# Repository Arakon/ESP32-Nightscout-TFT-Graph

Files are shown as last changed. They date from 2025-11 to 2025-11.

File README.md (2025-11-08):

# ESP32-Nightscout-TFT-Graph
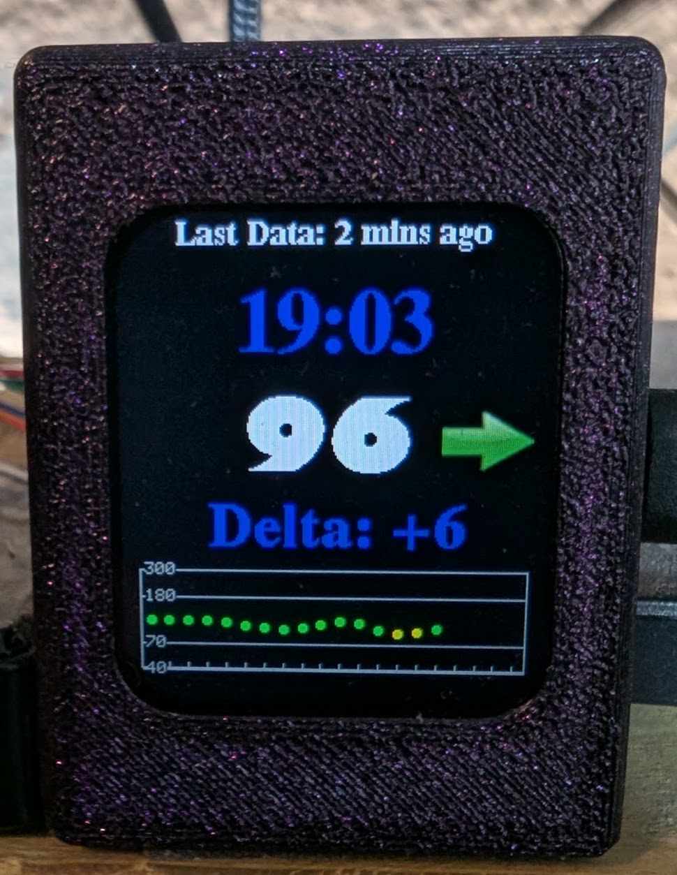
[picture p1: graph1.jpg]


ESP32-C3 based low cost desktop display for Nightscout Glucose

Display supported:

1.69" 240x280:
https://www.aliexpress.com/item/1005008136222795.html

ESP32-C3:
https://www.aliexpress.com/item/1005006599448997.html

[Wiring diagram](https://github.com/Arakon/ESP32-Nightscout-TFT-Graph/blob/main/wiring-C3.png)

If you want to flash the [binary](https://github.com/Arakon/ESP32-Nightscout-TFT-Graph/blob/main/ESP32-C3-Nightscout-TFT-Graph.bin) directly, get [esptool](https://github.com/espressif/esptool/releases/download/v4.10.0/esptool-v4.10.0-windows-amd64.zip), extract it, copy the ESP32-C3-Nightscout-TFT-Graph.bin to the same folder, then open a command prompt, navigate to the folder you extracted it to, and run:

`esptool --port COMxx write_flash 0x0 ESP32-C3-Nightscout-TFT-Graph.bin`

Replace "COMxx" with your COM port number of the ESP32-C3 (i.e. COM5)

Use Arduino IDE 2.3.5 or 2.3.6 to compile.

**Required libraries to install: LovyanGFX 1.2.7, ArduinoJSON 7.4.1, WiFiManger 2.0.17, ESP_MultiResetDetector 1.3.2**

Newer versions may work, but these are known working.

**It's critical that you install/downgrade the ESP32 Board version to _2.0.14_!**

Versions 3+ will not fit the available memory and also cause compile errors with LGFX, while versions >2.0.14 can cause a reset loop on the C3.

As board type, select the **LOLIN C3 Mini** if you are using the above ESP32-C3 SuperMini.

STL files are provided for the display, put the display in first so it is held by the hooks (note the indent, this is where the bottom of the display with the flex cable goes), put the plate on the back, then glue the ESP32-C3 into the provided space (thick doublesided tape recommended). Attach the plate on all 4 sides with a bit of hotglue. Finally, pop the lid on, noting the direction so that the button is above the ESP32's reset button.
If you need to get back in there for any reason, isopropyl alcohol will instantly release hotglue.
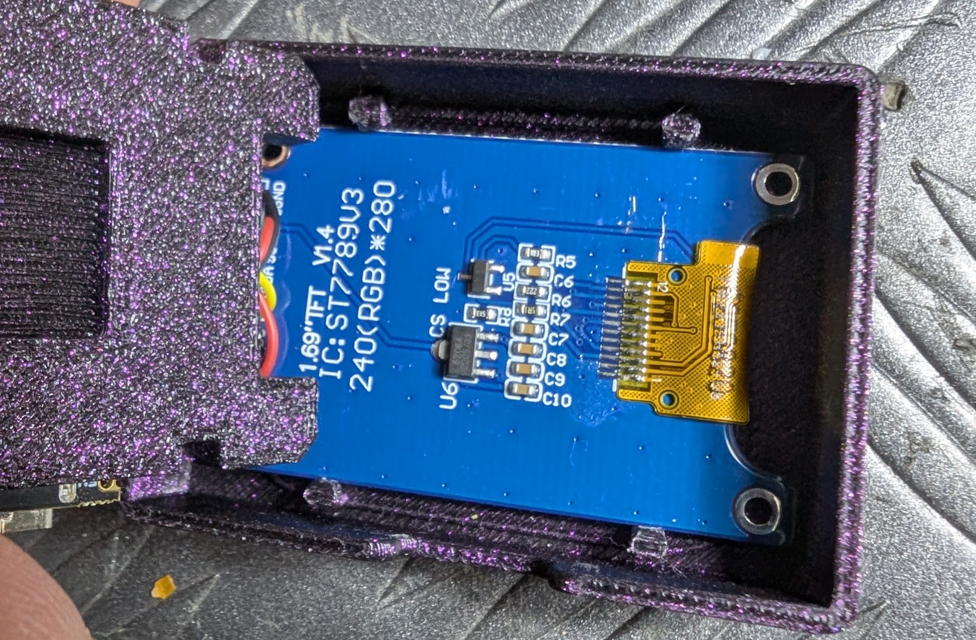
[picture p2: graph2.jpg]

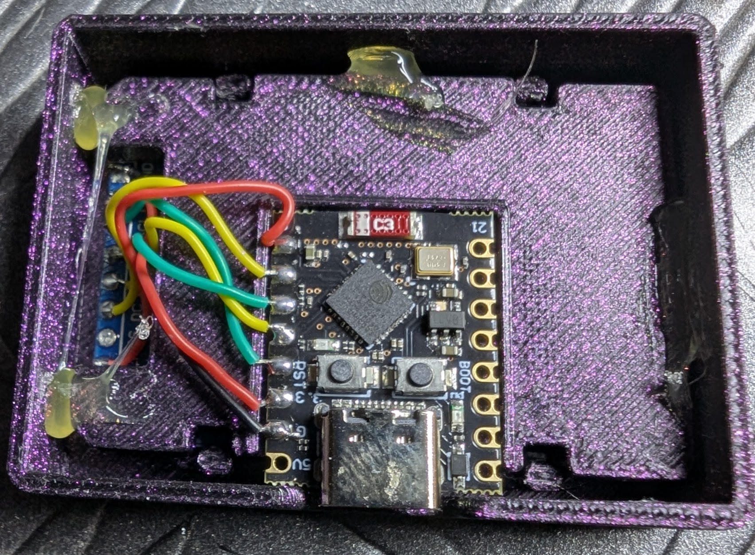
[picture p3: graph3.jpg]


Once the device starts for the first time, connect your WiFi (cellphone or PC) to the access point "Nightscout-TFT" that becomes available. Enter the password shown on the screen, then visit http://192.168.4.1 in your webbrowser.
You can set up your nightscout instance (add the _/pebble_ at the end like the example! You also need a [token with viewing rights](https://nightscout.github.io/nightscout/security/#create-a-token).) and your home WiFi there.

There is some oddity with the MultiResetDetector library that causes it to sometimes enter config mode when plugged in. Unplugging and plugging back in fixes this usually.

**First** run the Setup tab, with your Nightscout data, High/Low/Critical values and background light strength.

**Afterwards** you will have to reconnect to the access point again and this time, set up the WiFi connection.

Once everything is connected, you should get a full display. If it hangs, try unplugging, waiting for a moment, and plugging it back in.
If you ever want to change any of the options, quickly **tripleclick** the Reset button within 5 seconds on the ESP32 to force config mode. Wait for the yellow text before pressing the button each time. This will require you to connect to the Nightscout-TFT access point again with the password displayed on the screen.

The graph will populate as values arrive, it takes 100 minutes/20 updates to fully fill it.

Some status info is available on the serial monitor via USB (115200 baud).

Partially based on [Gluci-Clock](https://github.com/Frederic1000/gluci-clock/) and my own [Nightscout-TFT](https://github.com/Arakon/Nightscout-TFT).

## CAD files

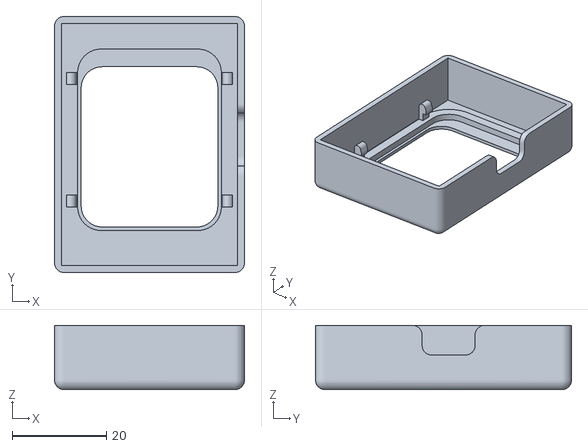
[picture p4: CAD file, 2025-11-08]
STL/case.stl
40.3 x 54.3 x 13.6

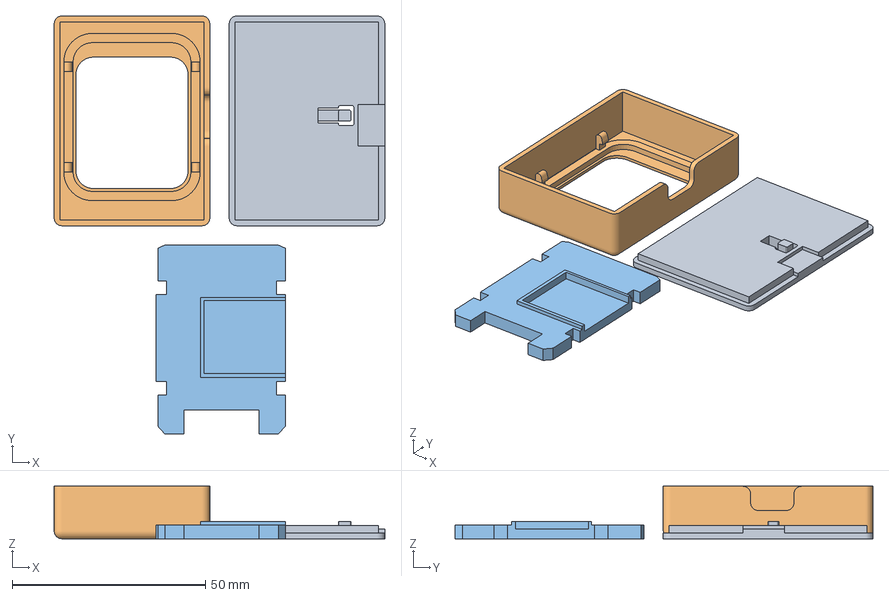
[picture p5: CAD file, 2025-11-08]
STL/1.69-Case.3mf
85.6 x 108.2 x 13.6 mm
lid.stl
case.stl
plate.stl

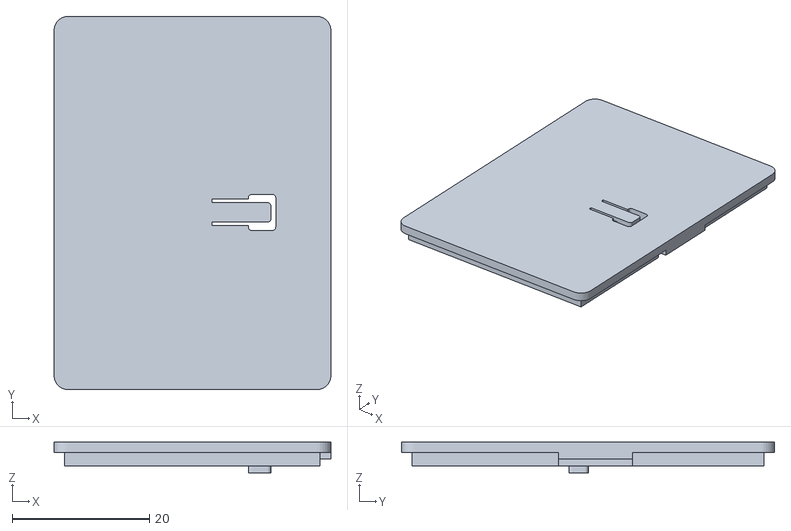
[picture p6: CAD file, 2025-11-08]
STL/lid.stl
40.3 x 54.3 x 4.50

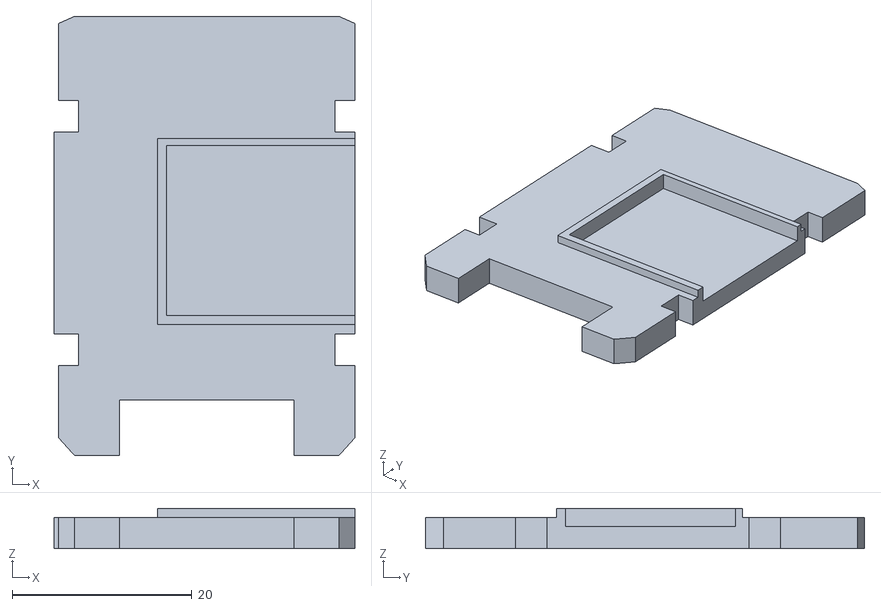
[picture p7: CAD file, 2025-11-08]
STL/plate.stl
33.5 x 48.9 x 4.50

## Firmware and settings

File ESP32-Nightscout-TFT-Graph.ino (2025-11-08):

/**
Nightscout glucose display for use with ESPS32-C3 and 1.3" or 1.54" SPI screen.
Based partially on my original version of this for ESP8266: https://github.com/Arakon/Nightscout-TFT
and gluci-clock by Frederic1000: https://github.com/Frederic1000/gluci-clock
Also compatible with other ESP32 devices, but may require pin reassignments below.

*/

// install libraries: WifiManager, arduinoJson, ESP_MultiResetDetector, LovyanGFX


// In the Arduino IDE, select Board Manager and downgrade to ESP32 2.0.14, ESP32 3.x based will NOT fit most smaller ESP32 boards anymore.

#include <Arduino.h>
#include <WiFi.h>
#include <FS.h>
#include <SPIFFS.h>
#include <HTTPClient.h>
#include <time.h>
#include <ArduinoJson.h>
#include <SPI.h>
#include <WiFiManager.h>

//including the arrow images
#include "Flat.h"
#include "DoubleDown.h"
#include "DoubleUp.h"
#include "FortyFiveUp.h"
#include "FortyFiveDown.h"
#include "Up.h"
#include "Down.h"
#define ESP_MRD_USE_SPIFFS true

#define GFXFF 1
#include <LovyanGFX.hpp>
#include "_19_font28pt7b.h"  //Numbers font for the Glucose number

//setup for LovyanGFX, all settings are in tft_config.h - Adjust to match your display if needed
#include "tft_config.h"
LGFX_Sprite sprite(&tft);

int hour_c;
int min_c;

// Defaults for when the color of the glucose value changes, edit them in the web interface
int HighBG = 180;
int LowBG = 90;
int CritBG = 70;

// --- Graph configuration ---
static const int GRAPH_WIDTH = 220;
static const int GRAPH_HEIGHT = 60;
static const int GRAPH_X = 10;
static const int GRAPH_Y = 200;

static const int MAX_POINTS = 20;
int sgv_values[MAX_POINTS] = { 0 };
int sgv_count = 0;

// -------------------------------------
// -------   Other Config   ------
// -------------------------------------

const int PIN_LED = LED_BUILTIN;  // default onboard LED
int backlight = 64;               //default brightness

#define JSON_CONFIG_FILE "/config.json"

// Number of seconds after reset during which a
// subseqent reset will be considered a triple reset.
#define MRD_TIMES 3
#define MRD_TIMEOUT 10
#define MRD_ADDRESS 0
#include <ESP_MultiResetDetector.h>
MultiResetDetector* mrd;
//flag for saving data
bool shouldSaveConfig = false;


// url and API key defaults for Nightscout - Set in the web portal
// We use the /pebble API since it contains the delta value. Don't remove the /pebble at the end!
char NS_API_URL[150] = "http://yournightscoutwebsite/pebble";

// Create a token with read access in NS > Hamburger menu > Admin tools
// Enter the token in the web portal
char NS_API_SECRET[50] = "view-123456790";


// Parameters for time NTP server
char ntpServer1[50] = "pool.ntp.org";
char ntpServer2[50] = "de.pool.ntp.org";

// Time zone for local time and daylight saving, edit in web interface
// list here:
// https://github.com/nayarsystems/posix_tz_db/blob/master/zones.csv
char local_time_zone[50] = "CET-1CEST,M3.5.0,M10.5.0/3";  // set for Europe/Berlin
char utc_time_zone[] = "GMT0";
int gmtOffset_sec = 3600;
long daylightOffset_sec = 3600;

// time zone offset in minutes, initialized to UTC
int tzOffset = 0;

void drawScreen(long sgv, int trend, int bg_delta, int elapsed_mn, const struct tm& tm) {
  sprite.fillScreen(TFT_BLACK);

  // ----------------------------
  // "Last Data" age display
  // ----------------------------
  int agecol = (elapsed_mn >= 15) ? TFT_RED : TFT_WHITE;  // change color if data is over 15 minutes old
  int agepos = (elapsed_mn >= 100)  ? 19                  // change position depending on number of digits
               : (elapsed_mn >= 10) ? 26
                                    : 33;

  sprite.setFont(&fonts::FreeSerifBold9pt7b);
  sprite.setTextColor(agecol, TFT_BLACK);
  sprite.setCursor(agepos, 4);
  sprite.printf("Last Data: %d min%s ago", elapsed_mn, (elapsed_mn == 1) ? "" : "s");  // add "s" to "mins" if >1

  // ----------------------------
  // Clock
  // ----------------------------
  sprite.setFont(&fonts::FreeSerifBold24pt7b);
  sprite.setTextColor(TFT_BLUE, TFT_BLACK);
  sprite.setCursor(65, 40);
  sprite.printf("%02d:%02d", tm.tm_hour, tm.tm_min);

  // ----------------------------
  // Glucose value
  // ----------------------------
  int bgcol = TFT_WHITE;
  if (sgv >= HighBG) bgcol = TFT_ORANGE;
  else if ((sgv <= LowBG) && (sgv > CritBG)) bgcol = TFT_YELLOW;
  else if (sgv <= CritBG) bgcol = TFT_RED;

  sprite.setFont(&_19_font28pt7b);
  sprite.setTextColor(bgcol, TFT_BLACK);
  sprite.setCursor((sgv < 100) ? 70 : 30, 100);  // adjust depending on whether the value has 2 or 3 digits
  sprite.println(sgv);

  // ----------------------------
  // Trend arrow
  // ----------------------------
  sprite.setSwapBytes(true);
  const uint16_t* arrowImg = nullptr;
  switch (trend) {
    case 1: arrowImg = DoubleUp; break;
    case 2: arrowImg = Up; break;
    case 3: arrowImg = FortyFiveUp; break;
    case 4: arrowImg = Flat; break;
    case 5: arrowImg = FortyFiveDown; break;
    case 6: arrowImg = Down; break;
    case 7: arrowImg = DoubleDown; break;
  }
  if (arrowImg) {
    sprite.pushImage(180, 100, 50, 50, arrowImg);
  }

  // ----------------------------
  // Delta
  // ----------------------------
  sprite.setFont(&fonts::FreeSerifBold18pt7b);
  sprite.setTextColor(TFT_BLUE, TFT_BLACK);
  sprite.setCursor((bg_delta >= 10) ? 37 : 49, 160);
  sprite.printf("Delta: %+d", bg_delta);
  drawSGVGraph(sprite);
  sprite.pushSprite(0, 0);
}

void drawSGVGraph(LGFX_Sprite& sprite) {

  // --- Define graph area ---
  int x0 = GRAPH_X;
  int y0 = GRAPH_Y;
  int w = GRAPH_WIDTH;
  int h = GRAPH_HEIGHT;

  // --- Clear graph area ---
  sprite.fillRect(x0, y0, w, h, TFT_BLACK);
  sprite.drawRect(x0, y0, w, h, TFT_DARKGREY);

  if (sgv_count == 0) return;

  const float MIN_SGV = 40.0f;
  const float MAX_SGV = 300.0f;
  const float LOG_BASE = 1.03f;
  auto logb = [&](float v) {
    return logf(v) / logf(LOG_BASE);
  };

  // compute consistent min/max
  float log_min = logb(MIN_SGV);
  float log_max = logb(MAX_SGV);

  // --- Draw Y-axis labels (SGV range) ---
  const int gridLevels[] = { 40, CritBG, HighBG, 300 };
  const int gridCount = sizeof(gridLevels) / sizeof(gridLevels[0]);
  sprite.setTextColor(TFT_DARKGREY, TFT_BLACK);
  sprite.setTextDatum(TL_DATUM);
  sprite.setFont(&fonts::Font0);
  for (int i = 0; i < gridCount; i++) {
    float log_val = logb(gridLevels[i]);
    float ratio = (log_val - log_min) / (log_max - log_min);
    int y = y0 + h - (int)(ratio * h);
    sprite.drawLine(x0 + 1, y, x0 + w - 1, y, TFT_DARKGREY);
    sprite.drawString(String(gridLevels[i]), x0 + 3, y - 4);
  }

  const float x_margin = w * 0.03f;  // 3% padding on each side
  const float usable_width = w - (2 * x_margin);
  const float xstep = usable_width / (MAX_POINTS - 1);

  // --- X-axis tick marks (each 5-min interval) ---
  for (int i = 0; i < MAX_POINTS; i++) {
    int x = x0 + x_margin + (int)(i * xstep);
    sprite.drawLine(x, y0 + h - 4, x, y0 + h, TFT_DARKGREY);
  }

  // --- Plot SGV points as filled circles ---
  for (int i = 0; i < sgv_count; i++) {
    int x = x0 + x_margin + (int)(i * xstep);
    float clamped_sgv = std::max(MIN_SGV, std::min(MAX_SGV, (float)sgv_values[i]));  //keep it from going out of range
    float log_val = logb(clamped_sgv);
    int y = y0 + h - (int)(((log_val - log_min) / (log_max - log_min)) * h);

    int dotcol = TFT_GREEN;
    if (sgv_values[i] >= HighBG) dotcol = TFT_ORANGE;
    else if ((sgv_values[i] <= LowBG) && (sgv_values[i] > CritBG)) dotcol = TFT_YELLOW;
    else if (sgv_values[i] <= CritBG) dotcol = TFT_RED;
    sprite.fillCircle(x, y, 2, dotcol);
  }
}

void serialPrintParams() {
  Serial.println("\tNS_API_URL : " + String(NS_API_URL));
  Serial.println("\tNS_API_SECRET: " + String(NS_API_SECRET));
  Serial.println("\tntpServer1 : " + String(ntpServer1));
  Serial.println("\tntpServer2 : " + String(ntpServer2));
  Serial.println("\tlocal_time_zone : " + String(local_time_zone));
  Serial.println("\tgmtOffset_sec : " + String(gmtOffset_sec));
  Serial.println("\tdaylightOffset_sec : " + String(daylightOffset_sec));
  Serial.println("\tbacklight : " + String(backlight));
  Serial.println("\tHigh BG : " + String(HighBG));
  Serial.println("\tLow BG : " + String(LowBG));
  Serial.println("\tCritical BG : " + String(CritBG));
}

void saveConfigFile() {
  Serial.println(F("Saving config"));
  StaticJsonDocument<256> json;

  json["NS_API_URL"] = NS_API_URL;
  json["NS_API_SECRET"] = NS_API_SECRET;
  json["ntpServer1"] = ntpServer1;
  json["ntpServer2"] = ntpServer2;
  json["local_time_zone"] = local_time_zone;
  json["gmtOffset_sec"] = gmtOffset_sec;
  json["daylightOffset_sec"] = daylightOffset_sec;
  json["backlight"] = backlight;
  json["HighBG"] = HighBG;
  json["LowBG"] = LowBG;
  json["CritBG"] = CritBG;

  File configFile = SPIFFS.open(JSON_CONFIG_FILE, "w");
  if (!configFile) {
    Serial.println("failed to open config file for writing");
  }

  serializeJsonPretty(json, Serial);
  if (serializeJson(json, configFile) == 0) {
    Serial.println(F("Failed to write to file"));
  }
  configFile.close();

  delay(3000);
  ESP.restart();
  delay(5000);
}

bool loadConfigFile() {
  Serial.println("mounting FS...");

  if (!SPIFFS.begin(false)) {  // mount existing FS
    Serial.println("SPIFFS mount failed, formatting...");
    delay(10);
    if (!SPIFFS.begin(true)) {  // format only if mount fails
      Serial.println("SPIFFS format failed!");
      return false;
    }
  }

  Serial.println("mounted file system");

  if (SPIFFS.exists(JSON_CONFIG_FILE)) {
    Serial.println("reading config file");
    File configFile = SPIFFS.open(JSON_CONFIG_FILE, "r");
    if (configFile) {
      StaticJsonDocument<256> json;
      DeserializationError error = deserializeJson(json, configFile);
      configFile.close();  // close immediately to release file handle

      serializeJsonPretty(json, Serial);

      if (!error) {
        backlight = json["backlight"];
        HighBG = json["HighBG"];
        LowBG = json["LowBG"];
        CritBG = json["CritBG"];
        strcpy(NS_API_URL, json["NS_API_URL"]);
        strcpy(NS_API_SECRET, json["NS_API_SECRET"]);
        strcpy(ntpServer1, json["ntpServer1"]);
        strcpy(ntpServer2, json["ntpServer2"]);
        strcpy(local_time_zone, json["local_time_zone"]);
        gmtOffset_sec = json["gmtOffset_sec"];
        daylightOffset_sec = json["daylightOffset_sec"];
        return true;
      } else {
        Serial.println("failed to load json config");
      }
    }
  }

  return false;
}


//callback notifying us of the need to save config
void saveConfigCallback() {
  Serial.println("Should save config");
  shouldSaveConfig = true;
}

WiFiManager wm;

// default password for Access Point, made from macID
char* getDefaultPassword() {
  // example:
  // const char * password = getDefaultPassword();

  // source for chipId: Espressif library example ChipId
  uint32_t chipId = 0;
  for (int i = 0; i < 17; i = i + 8) {
    chipId |= ((ESP.getEfuseMac() >> (40 - i)) & 0xff) << i;
  }
  chipId = chipId % 100000000;
  static char pw[9];  // with +1 char for end of chain
  sprintf(pw, "%08d", chipId);
  return pw;
}
const char* apPassword = getDefaultPassword();

//callback notifying us of the need to save parameters
void saveParamsCallback() {
  Serial.println("Should save params");
  shouldSaveConfig = true;
  wm.stopConfigPortal();  // will abort config portal after page is sent
}

// This gets called when the config mode is launched
void configModeCallback(WiFiManager* myWiFiManager) {
  Serial.println("Entered Conf Mode");
  Serial.print("Config SSID: ");
  Serial.println(myWiFiManager->getConfigPortalSSID());
  Serial.print("Config password: ");
  Serial.println(apPassword);
  Serial.print("Config IP Address: ");
  Serial.println(WiFi.softAPIP());

  // Show IP and password for initial setup
  tft.clear(0x000000u);
  tft.setCursor(10, 80);
  tft.setTextSize(2);
  tft.println("Please connect to: ");
  tft.println(WiFi.softAPIP());
  tft.setCursor(10, 130);
  tft.println("Password: ");
  tft.println(apPassword);
  tft.setTextSize(1);
}


/**
 * Set the timezone
 */
void setTimezone(char* timezone) {
  Serial.printf("  Setting Timezone to %s\n", timezone);
  configTzTime(timezone, ntpServer1, ntpServer2);
}

/**
 * Get time from internal clock
 * returns time for the timezone defined by setTimezone(char* timezone)
 */
struct tm getActualTzTime() {
  struct tm timeinfo = { 0 };
  if (!getLocalTime(&timeinfo)) {
    Serial.println("Failed to obtain time!");
    return (timeinfo);  // return {0} if error
  }
  Serial.print("System time: ");
  Serial.println(&timeinfo, "%A, %B %d %Y %H:%M:%S");
  return (timeinfo);
}

/**
 * Returns the offset in seconds between local time and UTC
 */
int getTzOffset(char* timezone) {

  // set timezone to UTC
  setTimezone(utc_time_zone);

  // and get tm struct
  struct tm tm_utc_now = getActualTzTime();

  // convert to time_t
  time_t t_utc_now = mktime(&tm_utc_now);

  // set timezone to local
  setTimezone(local_time_zone);

  // convert time_t to tm struct
  struct tm tm_local_now = *localtime(&t_utc_now);

  // set timezone back to UTC
  setTimezone(utc_time_zone);

  // convert tm to time_t
  time_t t_local_now = mktime(&tm_local_now);

  // calculate difference between the two time_t, in seconds
  int tzOffset = round(difftime(t_local_now, t_utc_now));
  Serial.printf("\nTzOffset : %d\n", tzOffset);

  return (tzOffset);
}
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
void loop() {
  mrd->loop();
  static int last_minute = -1;  // remembers the last minute we fetched data
  time_t now = time(nullptr);
  struct tm tm;
  localtime_r(&now, &tm);

  if (WiFi.status() != WL_CONNECTED) {
    delay(10);
    static unsigned long lastReconnectAttempt = 0;
    if (millis() - lastReconnectAttempt > 3000) {
      Serial.println("Reconnecting WiFi...");
      WiFi.reconnect();
      lastReconnectAttempt = millis();
    }
  }

  // Retrieve glucose data from NightScout Server
  if (tm.tm_min != last_minute) {
    last_minute = tm.tm_min;
    HTTPClient http;
    Serial.println("\n[HTTP] begin...");
    http.begin(NS_API_URL);  // fetch latest value
    http.addHeader("API-SECRET", NS_API_SECRET);
    Serial.print("[HTTP] GET...\n");

    // start connection and send HTTP header
    http.setConnectTimeout(10000);  // 10s
    http.setTimeout(10000);         // 10s
    int httpCode = http.GET();
    // httpCode will be negative on error
    if (httpCode > 0) {
      // HTTP header has been send and Server response header has been handled
      // NightScout data received from server
      if (httpCode == HTTP_CODE_OK) {
        String payload = http.getString();

        // parse NightScout data Json response
        StaticJsonDocument<512> filter;
        filter["bgs"][0]["sgv"] = true;
        filter["bgs"][0]["trend"] = true;
        filter["bgs"][0]["bgdelta"] = true;
        filter["bgs"][0]["datetime"] = true;
        filter["status"][0]["now"] = true;

        StaticJsonDocument<512> httpResponseBody;
        DeserializationError error = deserializeJson(httpResponseBody, payload, DeserializationOption::Filter(filter));

        // Test if parsing NightScout data succeeded
        if (error) {
          Serial.println();
          Serial.print(F("deserializeJson() failed: "));
          Serial.println(error.f_str());
        } else {

          // Get glucose values, trend, delta and timestamps
          long sgv = long(httpResponseBody["bgs"][0]["sgv"]);
          int trend = httpResponseBody["bgs"][0]["trend"];
          int bg_delta = httpResponseBody["bgs"][0]["bgdelta"];
          long long status0_now = httpResponseBody["status"][0]["now"];
          long long bgs0_datetime = httpResponseBody["bgs"][0]["datetime"];
          int elapsed_mn = (status0_now - bgs0_datetime) / 1000 / 60;

          if (sgv > 0) {  //only update if glucose value is valid
            if ((elapsed_mn == 0) || (elapsed_mn == 5)) {

              if (sgv_count < MAX_POINTS) {
                sgv_values[sgv_count++] = sgv;
              } else {
                // shift left, drop oldest
                for (int i = 0; i < MAX_POINTS - 1; i++) {
                  sgv_values[i] = sgv_values[i + 1];
                }
                sgv_values[MAX_POINTS - 1] = sgv;
              }
              Serial.printf("Appended SGV to history at minute %d (sgv=%ld)\n", tm.tm_min, sgv);
            }
            drawScreen(sgv, trend, bg_delta, elapsed_mn, tm);
            Serial.printf("%02d:%02d", tm.tm_hour, tm.tm_min);
            Serial.println();
            Serial.printf("Received Data, last update %d min%s ago", elapsed_mn, (elapsed_mn == 1) ? "" : "s");
          }
        }
      }

      else {
        Serial.printf("[HTTP] GET... failed, error: %s\n", http.errorToString(httpCode).c_str());
        delay(2000);  // prevent rapid retries
      }

      http.end();
    }
  }
}

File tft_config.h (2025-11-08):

class LGFX : public lgfx::LGFX_Device {
  lgfx::Panel_ST7789 _panel_instance;
  lgfx::Bus_SPI _bus_instance;
  lgfx::Light_PWM _light_instance;

public:
  LGFX(void) {
    {  // ---- SPI bus config ----
      auto cfg = _bus_instance.config();
      cfg.spi_host = SPI2_HOST;  // ESP32-C3 uses FSPI (SPI2_HOST)
      cfg.spi_mode = 3;
      cfg.freq_write = 40000000;  // matches your TFT_eSPI SPI_FREQUENCY
      cfg.freq_read = 20000000;   // matches your TFT_eSPI SPI_READ_FREQUENCY
      cfg.spi_3wire = true;
      cfg.use_lock = true;
      cfg.dma_channel = SPI_DMA_CH_AUTO;

      cfg.pin_sclk = 4;   // TFT_SCLK
      cfg.pin_mosi = 2;   // TFT_MOSI
      cfg.pin_miso = -1;  // no MISO on ST7789
      cfg.pin_dc = 1;     // TFT_DC

      _bus_instance.config(cfg);
      _panel_instance.setBus(&_bus_instance);
    }
    {  // ---- Panel config ----
      auto cfg = _panel_instance.config();
      cfg.pin_cs = -1;  // no CS defined in TFT_eSPI setup
      cfg.pin_rst = 3;  // TFT_RST
      cfg.pin_busy = -1;
      //quirk of this display: It has to be set to 240x320, but only 240x280 are actually visible
      cfg.memory_width = 240;
      cfg.memory_height = 320;
      cfg.panel_width = 240;
      cfg.panel_height = 320;
      cfg.offset_x = 0;
      cfg.offset_y = 20;
      cfg.offset_rotation = 0;
      cfg.invert = true;  // ST7789 usually needs this
      cfg.rgb_order = false;
      cfg.dlen_16bit = false;
      cfg.bus_shared = true;

      _panel_instance.config(cfg);
    }
    {  // ---- Backlight (if you have one) ----
      auto cfg = _light_instance.config();
      cfg.pin_bl = 0;  // backlight pin
      cfg.invert = false;
      cfg.freq = 44100;
      cfg.pwm_channel = 0;
      _light_instance.config(cfg);
      _panel_instance.setLight(&_light_instance);
    }
    setPanel(&_panel_instance);
  }
};

LGFX tft;
